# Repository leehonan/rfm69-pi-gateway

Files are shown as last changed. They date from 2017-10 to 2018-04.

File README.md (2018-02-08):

# Meterman Gateway (RFM69-to-Pi Gateway)

This repo contains PCB designs and firmware for a 'meter gateway' that communicates with one or more 'meter nodes' over packet radio.  It acts as a radio gateway between these and logic running on a local server.  Hardware consists of a ATMEGA 328P (with RFM69 radio), and a daughterboard to mate to a Raspberry Pi for Serial UART TX/RX and power (AKA a Pi Hat).  The PCB design could be used for a general-purpose RFM69-Pi Gateway, hacking the firmware code as needed.

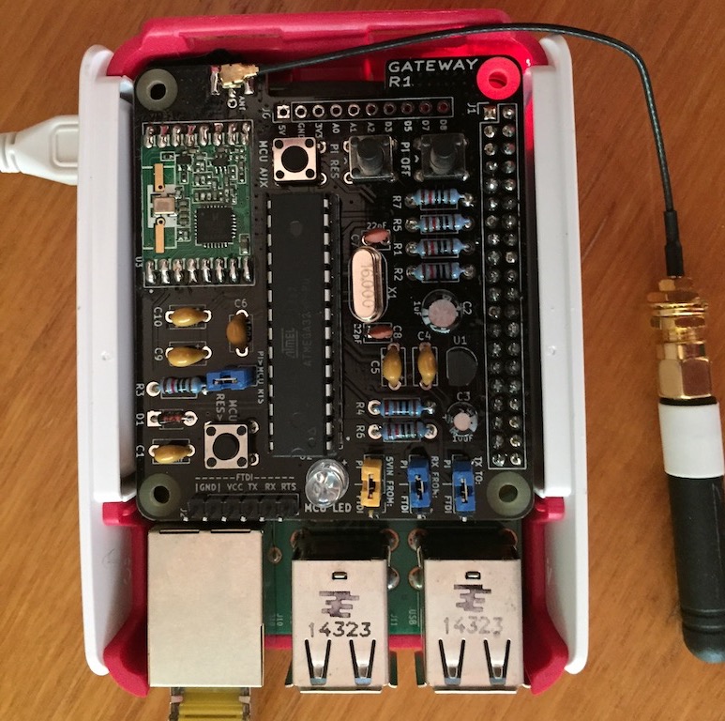
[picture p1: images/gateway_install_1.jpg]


(Note that as above a proper case is TBC)

This Gateway is part of a basic electricity monitoring system described at http://leehonan.com/meterman.  The 'MeterMan' system consists of:

* One or more [MeterNodes](https://github.com/leehonan/meterman-node), transmitting energy consumption at set intervals using sub-GHz packet radio (RFM69 @ 434/868/915MHz).

* The Gateway, being a Raspberry Pi 'Hat' that bridges the RFM69 network to a Raspberry Pi's UART Serial interface.

* A [Server](https://github.com/leehonan/meterman-server) that runs on the Pi, maintains energy consumption data, and provides access to this and other operational data through an API, a file journal, and a realtime socket API (socket API is TBD).

## This Repo

This (Gateway) repo consists of:

* The Gateway PCB design (authored in KiCad).  This mounts onto a Raspberry Pi, with ~12mm x 2.5mm spacers being recommended.

* 3D shape files (.STL) for the gateway housing (WIP).

* Source code for the Gateway firmware (AVR C with Arduino extensions).  

All contents are licenced according to the MIT licence.

## Gateway Overview
The Gateway is essentially a bridge between nodes on a RFM69 network and a local application connected to the Pi's UART serial port.  As the Gateway has been designed to support MeterNodes, much of the context for it is best understood by consulting the more comprehensive [MeterNode's ReadMe](https://github.com/leehonan/meterman-node/blob/master/readme.md) - it is not repeated here (DRY).

The Gateway itself comprises:
* A DC power sub-circuit, switchable using a jumper between 5V from the Raspberry Pi and FTDI (or off if no FTDI connection).  Uses a MCP1700 regulator to supply 3.3VDC.  

* An ATMega 328P MCU sub-circuit, along the lines of common 'minimal low-power Arduino' circuits.  FTDI Header for programming and control.

* A radio sub-circuit with an RFM69HW module.  The design uses an RP-SMA connector, but the PCB also supports uFL or a wire antenna.

The gateway does not have a 'real' RTC.  A timer-based clock is implemented in firmware, although this relies on regular synchronisation with its NTP-synced Pi (e.g. every 15m) to be accurate.

## Operation

 The Gateway:
* Polls for radio messages from nodes, responding to these as needed.  These may indicate events or status changes, which are passed through to the connected application (such as a meter update event).

* Keeps a register of meter nodes, maintaining state information and notifying the connected application when they appear to go offline.

* Polls for serial messages from the connected application, responding to these as needed.  Some of these will cause a particular instruction to be sent to a MeterNode(s) when they are available (e.g. to change their meter value).

* Sends messages to the connected application, such as a request from the Gateway to sync its clock.

The gateway runs continuously and does not sleep.  Its availability for radio messaging can therefore be depended upon by MeterNodes - hence all communication between MeterNodes and their Gateway is initiated by the MeterNodes.

### Gateway Hardware Interface
The MeterNode PCB has the following switches, buttons, headers, and adjustable components.  These are shown below.

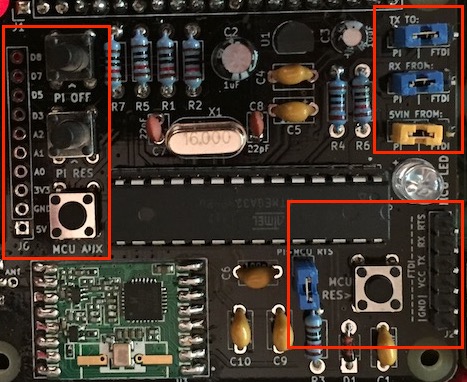
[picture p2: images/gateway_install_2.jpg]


* A group of 3 jumpers that toggle between the Pi and FTDI for TX from the MCU, RX by the MCU, and 5VDC In.  If the jumper is in the FTDI position but FTDI is not connected the device will be off.  Conversely if the switch is in the Pi position but a FTDI adapter is connected, power will be drawn from the Pi (with other FTDI functions working as normal).

* A 'Pi Off' button that shuts the Pi down (using the accompanying pi-gw-reboot script).

* A 'Pi Res' button that reboots the Pi (using the accompanying pi-gw-reboot script).

* A MCU Reset button that reboots the MCU.

* A MCU Aux button that can be programmed as needed (currently blinks LED).

* A jumper to allow the Pi to reboot the MCU (used when programming the MCU, safe to leave closed).

* An FTDI header for use with a USB-FTDI adapter.  This is used to upload firmware and also to interact with the MCU directly over a serial connection (viewing events and using the MeterNode's command protocol to view information and change settings).  Firmware can be uploaded using avrdude directly, or via an IDE (such as platform.io).  The use of the FTDI header is usually unnecessary with a Pi connected as all commands/operations can be performed from the Pi using its GPIO pins (assuming the enclosed scripts are installed).

* A breakout header that is used for setup and diagnosis, typically with a multimeter.  These can also be used for hacking together custom solutions.  The positions are described below and pictured above:

| Position | Description |
| :--- |:---|
| A0 - D8 | Access to unused analogue (A0 - A2) and digital (D3-D8) pins on the MCU. |
| GND | DC Ground. |
| 3V3 | 3.3VDC from regulator.  |
| 5V  | ~5VDC from Pi.  |

### Shutdown and Reboot
The Restart/Reboot and Shutdown buttons are connected to GPIO P23 and P24 (board numbering).  They perform a soft reboot or shutdown, equivalent to a `reboot` or `shutdown -h now`.

The enclosed pishutdown.py script needs to be installed for these to function, and to be set to start at boot.

A service script is enclosed in `/src`.  This can be installed as follows:
```
cp pishutdown.service /lib/systemd/system
chmod 644 /lib/systemd/system/pishutdown.service
systemctl daemon-reload
systemctl enable pishutdown.service
systemctl start pishutdown.service
```

Otherwise simple way to start on boot is to use cron, e.g.:
```
@reboot /usr/local/bin/python3.6 /home/pi/pishutdown.py
```

### Uploading Firmware
Firmware is uploaded using avrdude (alternately through an IDE such as atom/platform.io, the Arduino IDE may work too).  For an FTDI adapter with Id A403JXEV on OSX or Linux the command will be something like:

```
sudo avrdude -c arduino -p atmega328p -P /dev/cu.usbserial-A403JXEV -b 115200 -U flash:w:/home/tmp/firmware.hex
```
In practice for the gateway, it is easiest to upload firmware using scp and then to flash over the GPIO header using avrdude.  E.g.
```
scp /Users/lee/meter_gateway/firmware.hex meterman@meterbox:

sudo avrdude -c arduino -p atmega328p -P /dev/serial0 -b 115200 -U flash:w:/home/meterman/firmware.hex
```

For this to work, avrdude needs to be patched to work around the absence of a DTR pin on the RPi.  The files are enclosed in this repo's `/src` directory, and can be installed using the following commands (as sudo), or by executing the meterman setup script (from the meterman repo) on the pi.
```
cp autoreset /usr/bin
cp avrdude-autoreset /usr/bin
chmod +x /usr/bin/autoreset
chmod +x /usr/bin/avrdude-autoreset
mv /usr/bin/avrdude /usr/bin/avrdude-original
ln -s /usr/bin/avrdude-autoreset /usr/bin/avrdude
```

The flash process will only work if there are no active serial sessions on the port chosen.  Flashing fails occasionally for no clear reason, but will work when retried.

### Serial Communication & Console
A serial connection can be made using a baud of 115200bps, 8N1 (8 data bits, no parity bit, 1 stop bit).  

On the RPi minicom can be used (as can screen etc) to open a terminal:
```
sudo minicom -b 115200 -o -D /dev/serial0
```
Ensure that hardware flow control is off.

The following commands are available through the serial console (case-insensitive):

| Command | Description |
| :--- |:---|
| help | Prints a list of commands. |
| z  | Toggles sleep on and off. |
| dumpg | Prints (dumps) Gateway config and status to the console.  |
| dumpn | Prints (dumps) node status to the console (with dumpn=[node_id] to specify a node).  |
| rcfg | Reset Config.  Resets configuration values stored in EEPROM to defaults and re-applies these.  |
| time | Prints current time from RTC. Set using time=[seconds since UNIX epoch, UTC] |
| logl | Prints log level - ERROR, WARN, INFO, DEBUG.  Set with logl=[log level]|
| ekey | Prints encryption key (16 byte AES) used by network participants for radio comms.  Set with ekey=[encryption key], e.g. ekey=CHANGE_THIS_ASAP|
| neti | Prints Gateway's Network Id comprised of octets akin to an IP address but with an extra subnet (as the 4 octets define a subnet, with node addressing within this).  Set with neti=[network_id].  At least two octets need to be non-zero so 0.0.1.1 is the 'lowest' usable network subnet.  E.g. neti=0.0.1.1|
| gwid | Prints the 'node id' for the gateway.  This should be 1 by convention, but can be any unallocated address from 1 to 253. Set with gwid=[gateway Id]|
| txpw | Print/set transmission power (set with TXPW=[tx power in dBi]).  For RFM69W range is -18 to +13, for RFM69HW is -14 to +20. Higher values will use more power. |
| enta | Sets meter nodes to be in alignment mode (set on with ENTA=1, off with ENTA=0). When on, a change to a MeterNode's RTC will cause it to wait until mm:00 before opening a new entry.  |

### Pi-to-Gateway Serial Message Protocol
The serial port is also used for communication between the Pi and the Gateway.  In normal operation the user-driven command protocol should be unnecessary, as all key functions are exposed through this interface (intended to be used by the Meterman server application).

Messages are distinguished from user commands and user feedback/logging by a prefix:
* for a message from the Gateway to the Pi Server ```G>S:<message>```

* for a message from the Pi Server to the Gateway ```S>G:<message>```

| Message | From | To | Description|
| :--- |:---| :--- |:---|
| Get Time  | gateway | server | Request for server to return time, allowing gateway to sync its internal clock. <br>Format: `GTIME`<br>E.g.: `GTIME` |
| Set Time | server | gateway | Instruction to gateway to set its clock to the time provided (seconds since UNIX epoch) <br>Format: `STIME;<new_epoch_time_utc>`<br>E.g.: `STIME;1502795790`|
| Set Time Ack  | gateway | server | Acknowledges receipt of valid instruction.<br>Format: `STIME_ACK`<br>E.g.: `STIME_ACK` |
| Set Time Nack  | gateway | server | Negative acknowledgement of set time instruction, likely malformed. <br>Format: `STIME_NACK`<br>E.g.: `STIME_NACK` |
| Get Gateway Snapshot | server | gateway | Request for gateway status dump. <br>Format: `GGWSNAP`<br>E.g.: `GGWSNAP` |
| Gateway Snapshot | gateway | server | Dump of Gateway Status <br>Format: `GWSNAP;<gateway_id>,<when_booted>,<free_ram>,<time>,<log_level>,<encrypt_key>,<network_id>,<tx_power>`<br>E.g.: `GWSNAP;1,1496842913428,577,1496842913428,DEBUG,PLEASE_CHANGE_ME,0.0.1.1,13` |
| Get Node Snapshot | server | gateway | Requests a dump of a node's state from the Gateway.  All nodes observed by the gateway since boot will be returned (there is no registration process - any with correct subnet and key are assumed to be valid members). <br>Format: `GNOSNAP;<node_id> - returns all nodes if no node_id or node_id=254`<br>E.g.: `GNOSNAP;2` |
| Node Snapshot | gateway | server | A snapshot of one or more nodes, delimited by ';'. <br>Format: `NOSNAP;[1..n of [<node_id>,<batt_voltage>,<up_time>,<sleep_time>,<free_ram>,<when_last_seen>,<last_clock_drift>,<meter_interval>,<meter_impulses_per_kwh>,<last_meter_entry_finish>,<last_meter_value>,<puck_led_rate>,<puck_led_time>,<last_rssi_at_gateway>]]`<br>E.g.: `NOSNAP;2,4500,15000,20000,600,1496842913428,500,5,1496842913428,3050,1,100,1000,-70` |
| Get Node Snapshot Nack | gateway | server | Negative acknowledgement of request, likely malformed. <br>Format: `GNOSNAP_NACK;<node_id>`<br>E.g.: `GNOSNAP_NACK;2` |
| Meter Update - with Current | gateway | server | Pass-through of message from meterman node, with envelope. <br>Format: `MUPC;<node_id>,<MUPC radio message>`<br>E.g.: `MUPC;2,MUPC,1496842913428,18829393;15,1,10.2;15,5,10.7;` |
| Meter Update - without Current | gateway | server | Pass-through of message from meterman node, with envelope. <br>Format: `MUP_;<node_id>,<MUP_ radio message>`<br>E.g.: `MUP_;2,MUP_,1496842913428,18829393;15,1;15,5;15,2;16,3;` |
| Meter Rebase | gateway | server | Pass-through of message from meterman node, with envelope. <br>Format: `MREB;<node_id>,<MREB radio message>`<br>E.g.: `MREB;2,MREB,1496842913428,18829393` |
| General Message (Broadcast) | gateway | server | Pass-through of message from meterman node, with envelope. <br>Format: `GMSG;<node_id>,<GMSG radio message>`<br>E.g.: `GMSG;2,GMSG,message` |
| Set Meter Value | server | gateway | Requests a reset of a node's meter value to the watt-hour value specified <br>Format: `SMVAL;<node_id>,<new_meter_value>`<br>E.g.: `SMVAL;2,10` |
| Set Meter Value Ack | gateway | server | Acknowledges receipt of valid instruction. <br>Format: `SMVAL_ACK;<node_id>`<br>E.g.: `SMVAL_ACK;2` |
| Set Meter Value Nack | gateway | server | Negative acknowledgement of request, likely malformed. <br>Format: `SMVAL_NACK;<node_id>`<br>E.g.: `SMVAL_NACK;2` |
| Set Puck LED | server | gateway | Requests a change of a node's puck LED rate and time. <br>Format: `SPLED;<node_id>,<new_puck_led_rate>,<new_puck_led_time>`<br>E.g.: `SPLED;2,1,100` |
| Set Puck LED Ack | gateway | server | Acknowledges receipt of valid instruction. <br>Format: `SPLED_ACK;<node_id>`<br>E.g.: `SPLED_ACK;2` |
| Set Puck LED Nack | gateway | server | Negative acknowledgement of request, likely malformed. <br>Format: `SPLED_NACK;<node_id>`<br>E.g.: `SPLED_NACK;2` |
| Set Meter Interval | server | gateway | Requests a change of a node's metering interval to the value specified.  The interval is the period in seconds at which meter entries are created i.e. (resolution). <br>Format: `SMINT;<node_id>,<new_meter_interval>`<br>E.g.: `SMINT;2,10` |
| Set Meter Interval Ack | gateway | server | Acknowledges receipt of valid instruction. <br>Format: `SMINT_ACK;<node_id>`<br>E.g.: `SMINT_ACK;2` |
| Set Meter Interval Nack | gateway | server | Negative acknowledgement of request, likely malformed. <br>Format: `SMINT_NACK;<node_id>`<br>E.g.: `SMINT_NACK;2` |
| Set GITR | server | gateway | Sends request to gateway to set node's gateway instruction polling rate to more aggressive value for a temporary period <br>Format: `SGITR;<node_id>,<tmp_poll_rate>,<tmp_poll_period>`<br>E.g.: `SGITR;2,30,300` |
| Set GITR Ack | gateway | server | Acknowledges receipt of valid instruction. <br>Format: `SGITR_ACK;<node_id>`<br>E.g.: `SGITR_ACK;2` |
| Set GITR Nack | gateway | server | Negative acknowledgement of request, likely malformed. <br>Format: `SGITR_NACK;<node_id>`<br>E.g.: `SGITR_NACK;2` |
| Node Dark Alert | gateway | server | One-time alert on node going from seen to 'missing' after configured period <br>Format: `NDARK;<node_id>,<last_seen>`<br>E.g.: `NDARK;2,1496842913428` |

### Radio Protocol
See the <a href="https://github.com/leehonan/meterman-node/blob/master/readme.md#radio-protocol">MeterNode Radio Protocol documentation</a>.

## Implementation - Gateway Firmware
For simplicity, the firmware is implemented as a single C++ program (no header file), although it will need supporting libraries to compile.  There is some redundancy versus the companion meternode firmware - the common components may be moved to a library.  Some Arduino library features are used.

The firmware requires a 328P that has been flashed with Optiboot.  It uses about 90% available program flash memory.

Depending on configuration, about 500 bytes RAM will remain free at runtime (on average, of 2K).  

There are a number of configuration settings at the beginning of the source code.  Particular attention should be paid to the 'Main Config Parameters'.

Note that a version is set in the firmware, and broadcast on boot.

The code is fairly well-documented so isn't covered further here.

## Implementation - PCBs & Cases

The Gateway PCB measures 65x56mm, being a standard Raspberry Pi Hat size.

A case for the Pi and Gateway is TBD, currently I use a regular Pi case and tape the antenna to it.

Of course, the MeterNode and Gateway antennae should be in the same orientation to maximise signal strength.

### Gateway Schematic & PCB

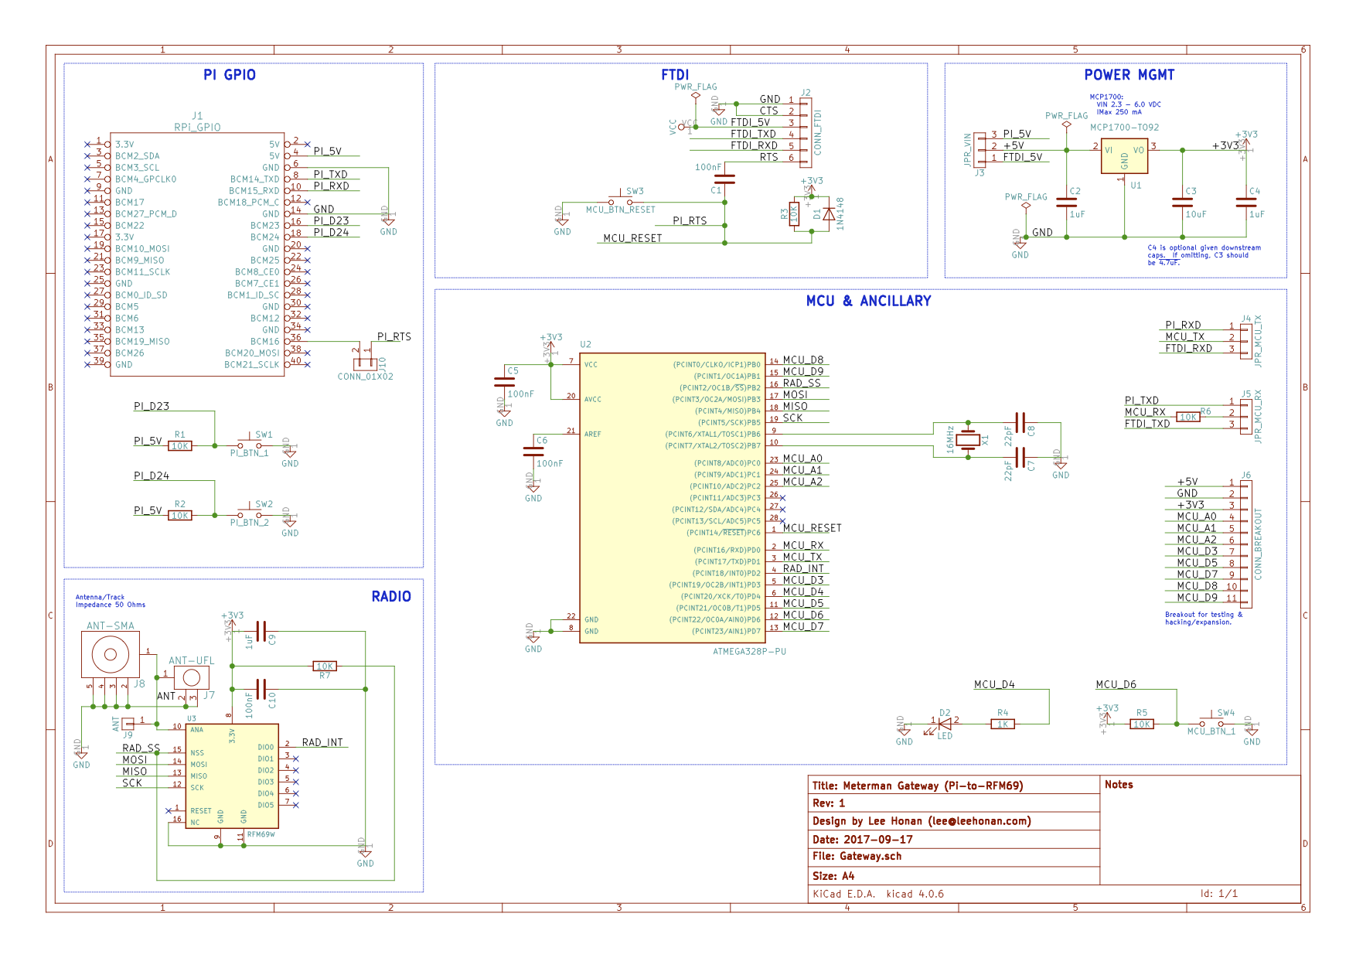
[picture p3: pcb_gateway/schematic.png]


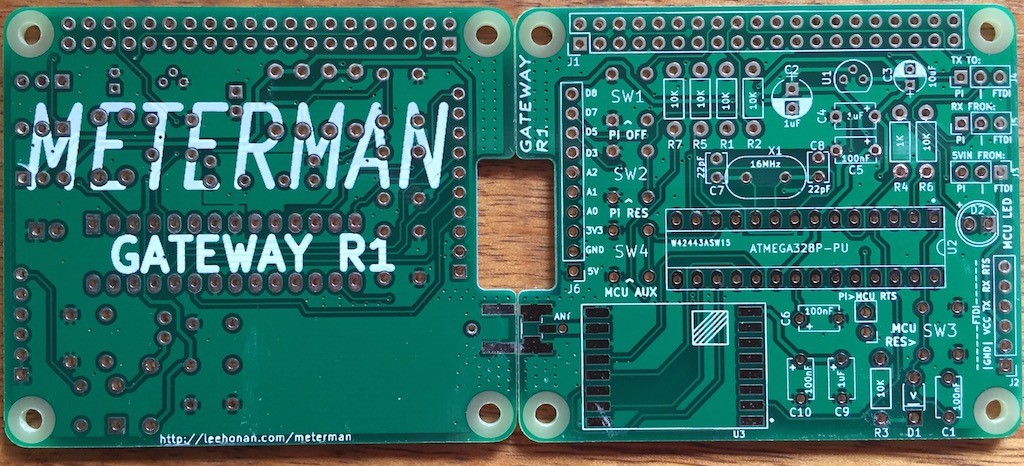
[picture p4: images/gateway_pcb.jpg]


The PCB design minimises the use of SMT components, and uses through-hole instead.  It is 'hobbyist-friendly' with the only SMT component being the easily-solderable RFM69 and the slightly fiddly uFL connector.  

Highlights:

* The MCP1700 regulator (3.3V) was chosen for consistency with the MeterNode.

* Unlike the MeterNode, I usually use a uFL connector here.  Of course a RP-SMA connector, or even a wire of the appropriate length can be used instead.

* Any RFM69W or RFM69HW module will work.  I use the RFM69HW here (as opposed to the MeterNode's RFM69W) because it is cheaper and there is no need to minimise power consumption on the gateway.

* Of course, the Pi's 2x20 GPIO header needs to face downward (towards the Pi).  Be mindful of this when assembling.

### Parts List

Approx total is USD$11 (not including labour!).  That assumes you purchase common parts in quantity from Chinese suppliers (e.g. resistors, capacitors).  Otherwise cost will be radically higher.  

| Part | Qty | Approx <br>Item Cost<br>(USD) | Comments |
|:---| :--- |:---|:---|
| PCB | 1 | $0.50 | E.g. 10 for $5 at PCBWay |
| Case | 1 | $0.50 | 3D-printed, PLA |
| LED | 1 | $0.02 | Super-bright 5mm, 20mA |
| RP-SMA 3dbi Antenna | 1 | $2.90 | I use higher quality ones via RocketScream, cheaper options available. |
| uFL Connector w/ pigtail | 1 | $1.00 |  |
| MCP1700 Regulator | 1 | $0.50 | 3.3V, TO-92 |
| MCU - ATMEGA 328P | 1 | $1.80 | DIP-28, with holder |
| 16MHz Crystal | 1 | $0.20 | |
| RFM69HW Module | 1 | $2.50 | SMD |
| Resistor - 1 KOhm | 1 | $0.01 | 0.25W |
| Resistor - 10 KOhm | 6 | $0.01 | 0.25W |
| Capacitor - 22 pF | 2 | $0.01 | Ceramic disc |
| Capacitor - 100 nF | 4 | $0.01 | Monolithic, Ceramic |
| Capacitor - 1 uF | 1 | $0.02 | Electrolytic |
| Capacitor - 1 uF | 2 | $0.01 | Monolithic, Ceramic |
| Capacitor - 10 uF | 1 | $0.02 | Electrolytic, 4x7mm |
| Diode - 1N4148 | 1 | $0.01 |  |
| 6x6mm pushbutton | 4 | $0.02 |  |
| Pin Header | 1 | $0.02 | 6P, 2.54mm pitch |
| Pin Header | 3 | $0.01 | 3P, 2.54mm pitch |
| Pin Header | 1 | $0.01 | 2P, 2.54mm pitch |
| Jumper Cap | 4 | $0.01 | 2P, 2.54mm pitch |
| Pi GPIO Header | 1 | $0.10 | 2x20, 40P, 2.54mm pitch |

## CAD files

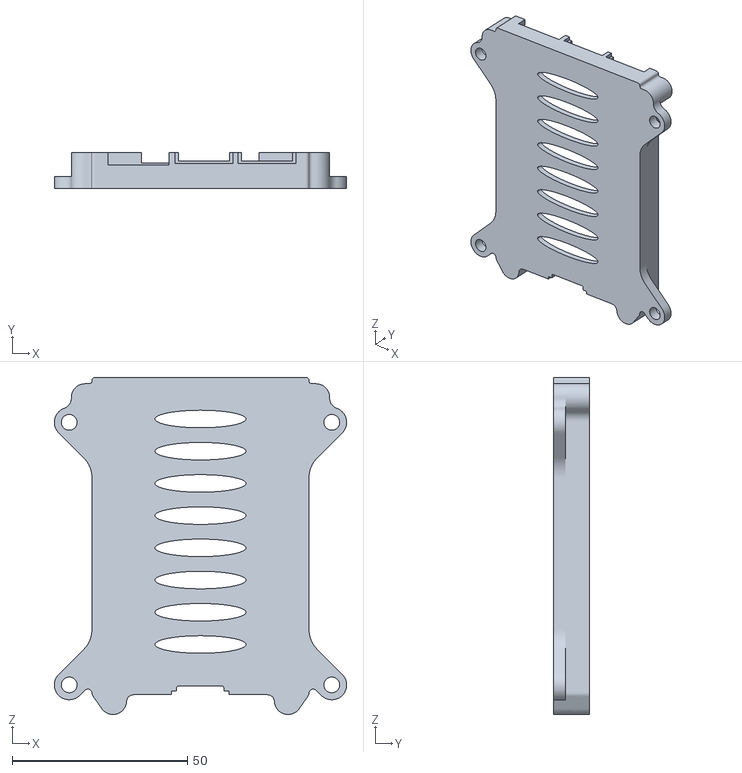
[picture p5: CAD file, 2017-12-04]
pcb_gateway/3D Parts/Base.stl
83.5 x 10.3 x 96.2

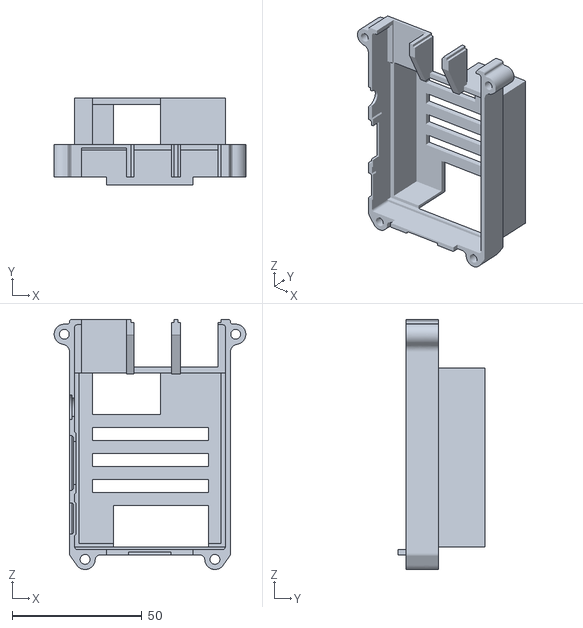
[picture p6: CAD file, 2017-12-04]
pcb_gateway/3D Parts/Lid.stl
73.8 x 33.5 x 96.3

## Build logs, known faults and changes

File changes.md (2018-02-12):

# Change Log

Release/revision numbering is major only, no minors - i.e. 1,2,3... not 1.1, 1.2, 2.0, etc.

#### 2017-11-27 R6
* Baseline release to GitHub (from private repo).

#### 2018-01-22 R8
* Changed sscanf calls to use SCNu8 macro for uint_8t vars, SCNd8 macro for int_8t vars

#### 2018-02-06 R9
* Reduced default modem baud rate to 9.6kbps

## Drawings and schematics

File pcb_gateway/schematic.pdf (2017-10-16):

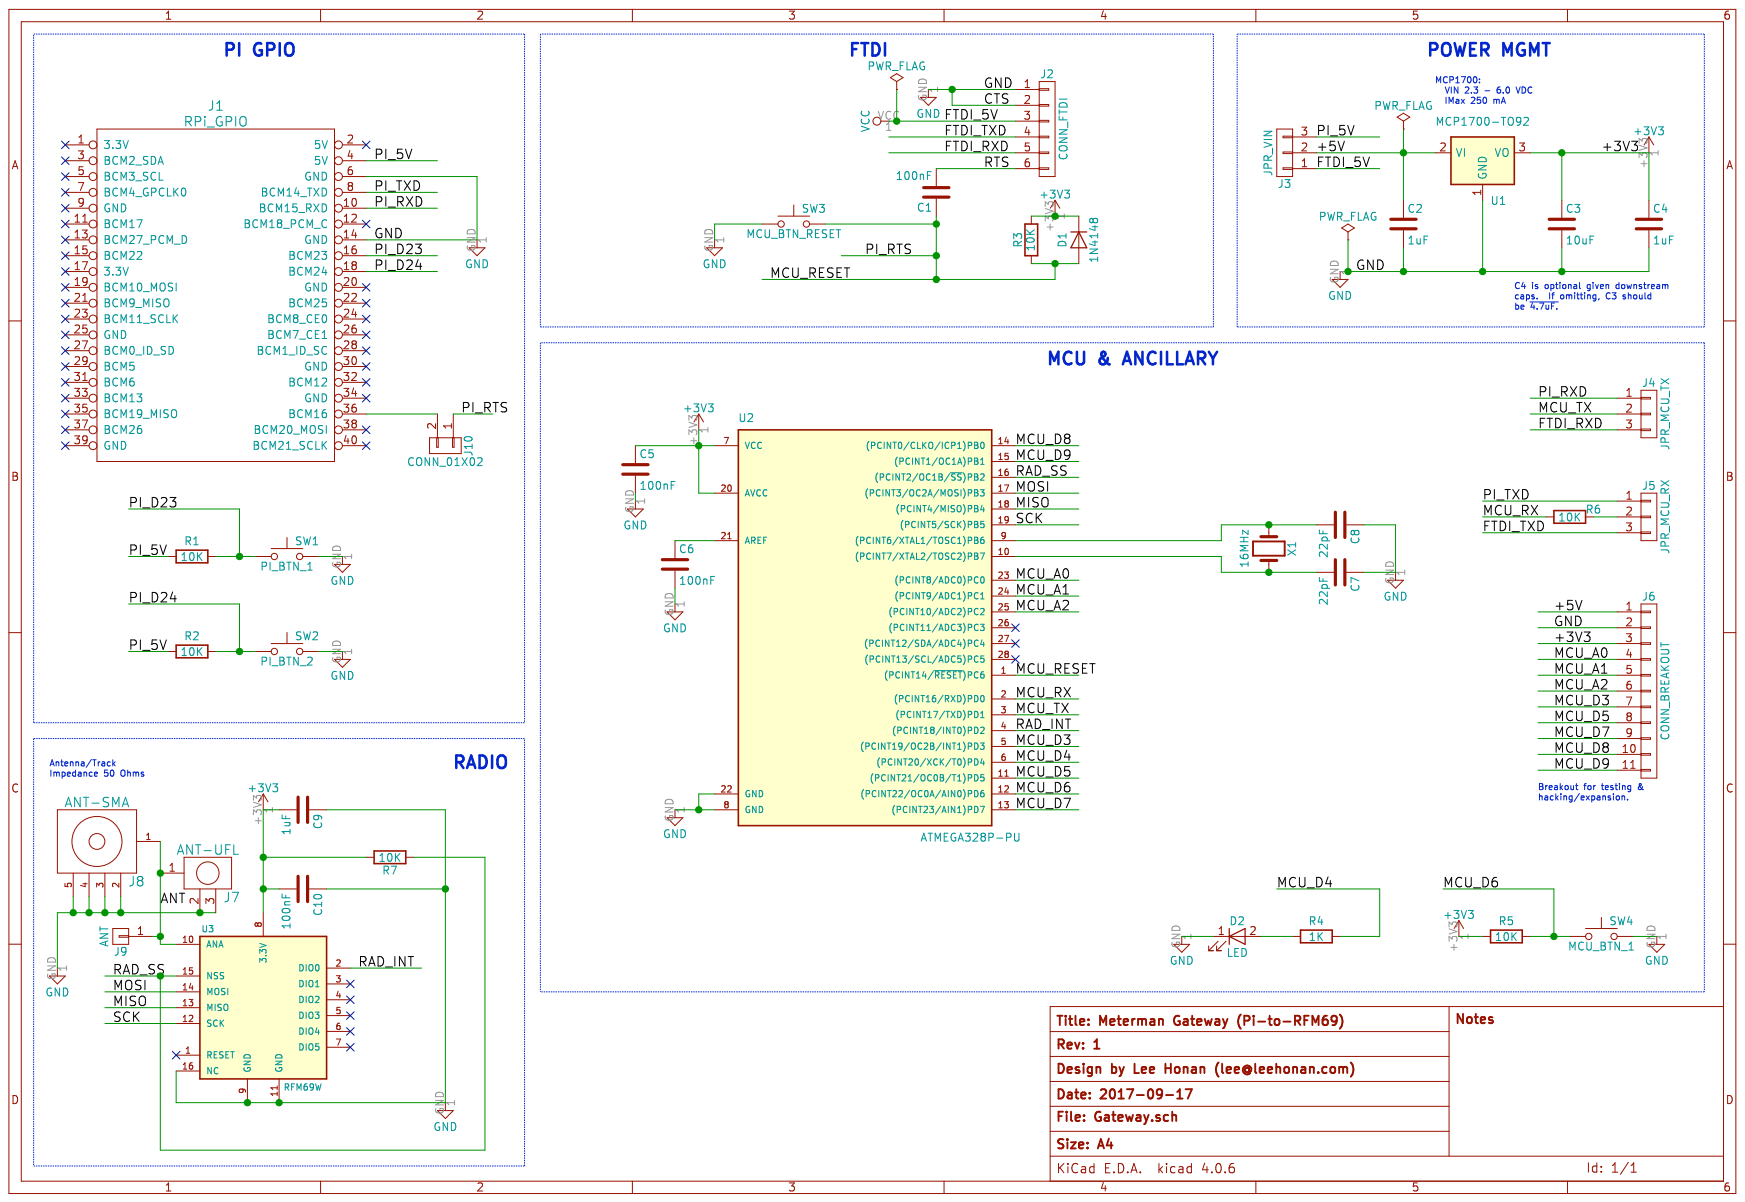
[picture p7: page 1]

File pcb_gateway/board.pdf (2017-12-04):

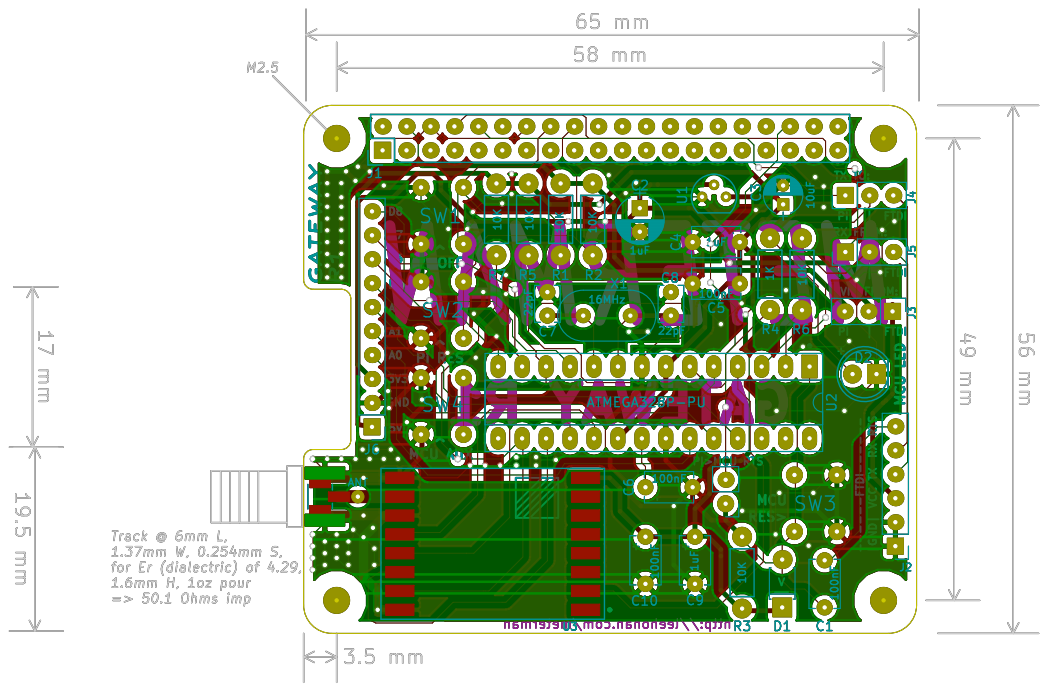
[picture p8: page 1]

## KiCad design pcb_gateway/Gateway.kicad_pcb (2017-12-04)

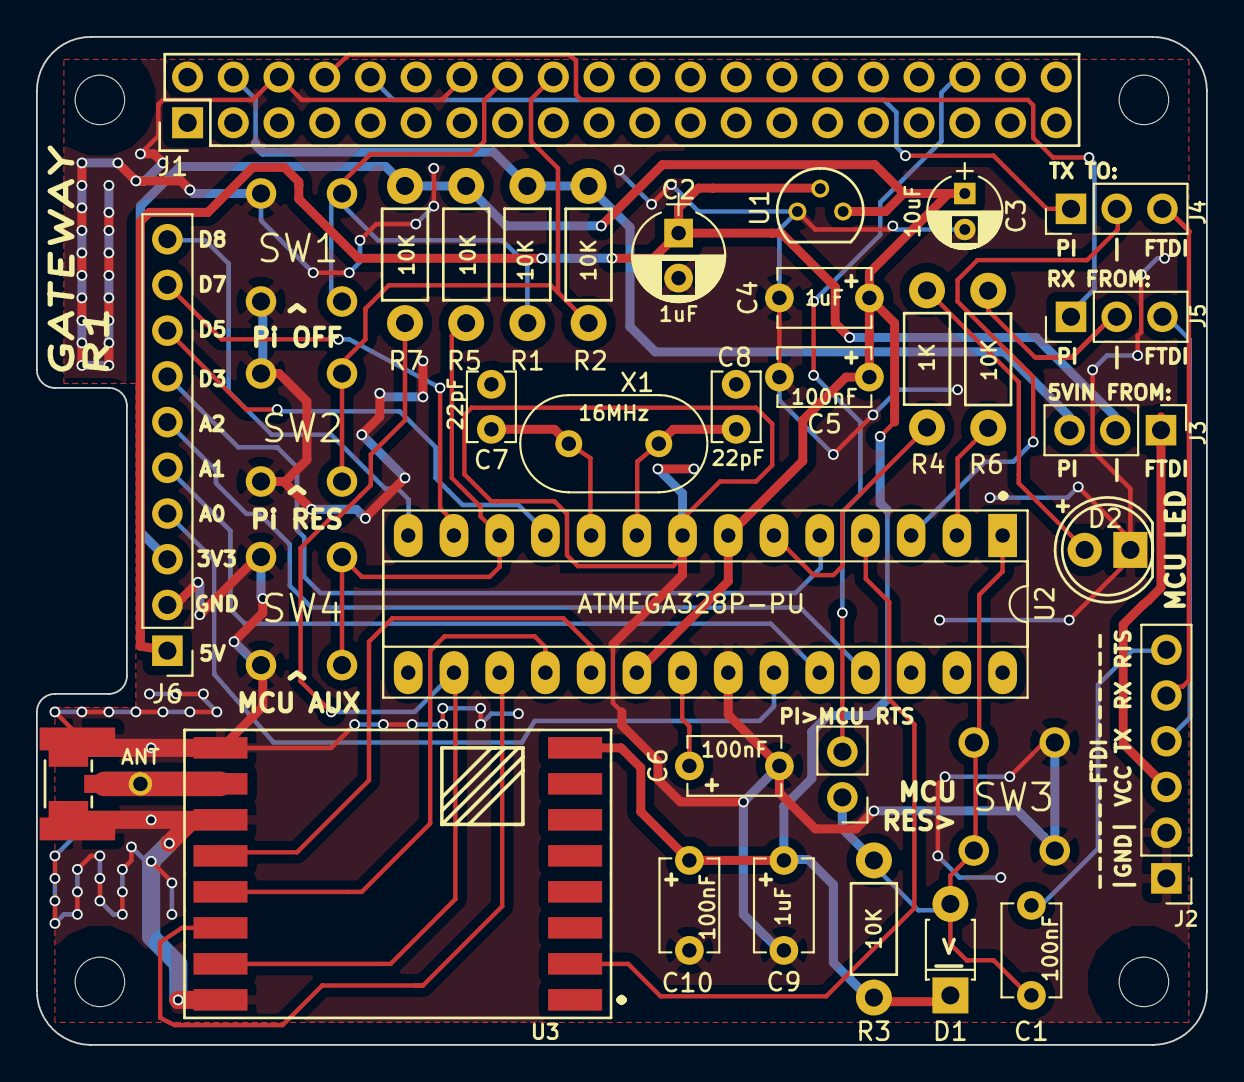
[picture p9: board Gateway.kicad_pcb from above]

Board: 2 copper layers, 65.0 x 56.0 mm, 37 parts (0 on the bottom side), 36 nets.

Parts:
C1, C5, C6, C10: 100nF; C_Disc_D5.1mm_W3.2mm_P5.00mm
C2: 1uF; CP_Radial_D5.0mm_P2.50mm
C3: 10uF; CP_Radial_D4.0mm_P2.00mm
C4, C9: 1uF; C_Disc_D5.1mm_W3.2mm_P5.00mm
C7, C8: 22pF; C_Disc_D3.8mm_W2.6mm_P2.50mm
D1: 1N4148; D_T-1_P5.08mm_Horizontal
D2: LED; LED-5MM
J1: RPi_GPIO; Pin_Header_Straight_2x20
J2: CONN_FTDI; Pin_Header_Straight_1x06_Pitch2.54mm
J3: JPR_VIN; Pin_Header_Straight_1x03_Pitch2.54mm
J4: JPR_MCU_TX; Pin_Header_Straight_1x03_Pitch2.54mm
J5: JPR_MCU_RX; Pin_Header_Straight_1x03_Pitch2.54mm
J6: CONN_BREAKOUT; Pin_Header_Straight_1x10_Pitch2.54mm
J7: ANT-UFL; U.FL-R-SMT
J8: ANT-SMA; RF-SMA-EDGE
J9: ANT; Pin_Header_Straight_1x01
J10: CONN_01X02; Pin_Header_Straight_1x02_Pitch2.54mm
R1, R2, R3, R5, R6, R7: 10K; Resistor_Horizontal_RM7mm
R4: 1K; Resistor_Horizontal_RM7mm
SW1: PI_BTN_1; 6x6mm_pushbutton
SW2: PI_BTN_2; 6x6mm_pushbutton
SW3: MCU_BTN_RESET; 6x6mm_pushbutton
SW4: MCU_BTN_1; 6x6mm_pushbutton
U1: MCP1700-TO92; TO-92_Molded_Narrow
U2: ATMEGA328P-PU; DIP-28_W7.62mm_Socket_LongPads
U3: RFM69W; RFM69HW_SMD_Handsoldering
X1: 16MHz; Resonator-2pin_w10.0mm_h5.0mm

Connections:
+3V3: C3.1, C4.1, C5.1, C9.2, C10.2, D1.1, J6.3, R3.2, R5.2, R7.2, U1.3, U2.7, U2.20, U3.8
/+5V: C2.1, J3.2, J6.1, U1.2
/ANT: J7.1, J9.1, U3.10
/FTDI_RXD: J2.5, J4.3
/FTDI_TXD: J2.4, J5.3
/MCU_A0: J6.4, U2.23
/MCU_A1: J6.5, U2.24
/MCU_A2: J6.6, U2.25
/MCU_D3: J6.7, U2.5
/MCU_D4: R4.1, U2.6
/MCU_D5: J6.8, U2.11
/MCU_D6: R5.1, SW4.1, U2.12
/MCU_D7: J6.9, U2.13
/MCU_D8: J6.10, U2.14
/MCU_RESET: C1.1, D1.2, J10.1, R3.1, SW3.2, U2.1
/MCU_RX: R6.2, U2.2
/MCU_TX: J4.2, U2.3
/MISO: U2.18, U3.13
/MOSI: U2.17, U3.14
/PI_5V: J1.4, J3.3, R1.2, R2.2
/PI_D23: J1.16, R1.1, SW1.1
/PI_D24: J1.18, R2.1, SW2.1
/PI_RXD: J1.10, J4.1
/PI_TXD: J1.8, J5.1
/RAD_INT: U2.4, U3.2
/RAD_SS: R7.1, U2.16, U3.15
/RTS: C1.2, J2.6
/SCK: U2.19, U3.12
GND: C2.2, C3.2, C4.2, C5.2, C6.2, C7.1, C8.1, C9.1, C10.1, D2.1, J1.6, J1.14, J2.1, J2.2, J6.2, J7.2, J7.3, J8.2, J8.3, J8.4, J8.5, SW1.2, SW2.2, SW3.1, SW4.2, U1.1, U2.8, U2.22, U3.9, U3.11, U3.16
unnamed: C6.1, U2.21
unnamed: C7.2, U2.10, X1.2
unnamed: C8.2, U2.9, X1.1
unnamed: D2.2, R4.2
unnamed: J1.36, J10.2
unnamed: J5.2, R6.1
VCC: J2.3, J3.1

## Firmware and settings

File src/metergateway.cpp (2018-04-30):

/**
    =========
    METERMAN METERGATEWAY
    metergateway.cpp
    =========
    Operates a 'meter gateway' that communicates with one or more 'meter nodes'
    over packet radio.  It acts as a radio gateway between these and logic
    running on a local server.  Hardware consists of a ATMEGA 328P (with RFM69
    radio), and a daughterboard to mate to a Raspberry Pi for Serial TX/RX and
    power (AKA a Pi Hat).

    This gateway could aggregate multiple nodes. These are part of a basic
    monitoring system as described at http://leehonan.com/meterman.

    Uses following libraries (with licencing):  RadioHead (GPL Version 2
    Licence), and Time (GPL 2.1).

    This program is licenced as follows.

    -----------
    MIT License
    -----------

    Copyright (c) 2017 Lee Honan (lee at leehonan dot com).

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
    THE SOFTWARE IS PROVIDED "AS IS", WITHOUT WARRANTY OF ANY KIND, EXPRESS OR
    IMPLIED, INCLUDING BUT NOT LIMITED TO THE WARRANTIES OF MERCHANTABILITY,
    FITNESS FOR A PARTICULAR PURPOSE AND NONINFRINGEMENT. IN NO EVENT SHALL THE
    AUTHORS OR COPYRIGHT HOLDERS BE LIABLE FOR ANY CLAIM, DAMAGES OR OTHER
    LIABILITY, WHETHER IN AN ACTION OF CONTRACT, TORT OR OTHERWISE, ARISING
    FROM, OUT OF OR IN CONNECTION WITH THE SOFTWARE OR THE USE OR OTHER DEALINGS
    IN THE SOFTWARE.
 */

// *****************************************************************************
//    Main Config Parameters
//    'DEF_*' constants are defaults for configuration variables of the same
//    name. Most of these will be stored to EEPROM and can be updated by
//    serial terminal commands.

//    Have minimised use of #DEFINE, #IFDEF etc for easier debugging.
// *****************************************************************************

#include <Arduino.h>
#include <avr/wdt.h>
#include <EEPROM.h>

// http://www.airspayce.com/mikem/arduino/RadioHead/
#include <RH_RF69.h>
#include <RHReliableDatagram.h>

// https://github.com/PaulStoffregen/Time
#include <TimeLib.h>


static const int8_t FW_VERSION = 10;

// Log Levels
typedef enum {
    logNull = 0,        // outputs to serial regardless of runtime log level
    logError = 1,
    logWarn = 2,
    logInfo = 3,
    logDebug = 4
} LogLev;

// Default runtime log level.
// Can control through serial command, save to EEPROM.
static const LogLev DEF_LOG_LEVEL = logDebug;

// if using HW/HCW module must set to true:
static const bool RADIO_HIGH_POWER = true;

// Initial power level in dBm.  Use -18 to +13 for W/CW, -2 to +20 for HW/HCW:
static const int8_t DEF_TX_POWER = 19;

// Gateway ID.  Gateway is usually 1.  Nodes between 2 and 254.
// 255 is broadcast (RH_GMSG_ADDRESS).
// Nodes are added dynamically, no pre-registration.
// Implicitly trusted if they have the same network Id and key.
static const uint8_t DEF_GATEWAY_ID = 1;

// Network octets, akin to IP address but with an extra subnet (as the 4 octets
// define a subnet, with node addressing within this).
// Need at least 2 octets to be non-zero, so will have 3rd and 4th begin at 1.
static const uint8_t DEF_NETWORK_ID_O1 = 0;  //0 to 254
static const uint8_t DEF_NETWORK_ID_O2 = 0;  //0 to 254
static const uint8_t DEF_NETWORK_ID_O3 = 1;  //1 to 254 by convention
static const uint8_t DEF_NETWORK_ID_O4 = 1;  //1 to 254 by convention

// AES 128b encryption key, shared amongst nodes.  Must be 16 chars/bytes,
// chars ASCII 32 - 126 (space, symbols, letters, numbers).
static const uint8_t KEY_LENGTH = 16;
static const uint8_t DEF_ENCRYPT_KEY[KEY_LENGTH] =
        {'C','H','A','N','G','E','_','M','E','_','P','L','E','A','S','E'};

static const uint32_t SERIAL_BAUD = 115200;

// whether to align node entries to mm:00 (begin at top of minute)
static const bool DEF_ALIGN_ENTRIES = 1;

// *****************************************************************************
//    General Init - Pins
// *****************************************************************************

static const uint8_t RADIO_INTERRUPT_PIN = 2;   // IC4
                                                // uses 328P interrupt 0

static const uint8_t RADIO_SS_PIN = 10;         // IC16
                                                // HIGH is off, LOW on

static const uint8_t LED_PIN = 4;               // IC6

static const uint8_t BUTTON_PIN = 6;            // IC12
                                                // auxiliary button

// *****************************************************************************
//    General Init - General Variables
// *****************************************************************************

// variable to hold MCU reset cause
uint8_t resetFlags __attribute__ ((section(".noinit")));

uint32_t btnEventStartMillis = 0;    // button on start time in millis

// global temporary variables, used somewhat arbitrarily vs local static vars
char tmpStr[60] = "";
uint32_t tmpInt = 0ul;

static const uint8_t SERIAL_IN_BUFFER_SIZE = 40;
char serInBuff[SERIAL_IN_BUFFER_SIZE] = "";
uint8_t serialBuffPos = 0;

// *****************************************************************************
//    General Init - Config Vars
// *****************************************************************************

// Config Variables (corresponding defaults are defined above with DEF_*).  Can
// be changed with serial commands and are saved to EEPROM.
LogLev cfgLogLevel = DEF_LOG_LEVEL;
uint8_t cfgTXPower = 0;
uint8_t cfgGatewayId = 0;
uint8_t cfgNetworkId1 = 0;
uint8_t cfgNetworkId2 = 0;
uint8_t cfgNetworkId3 = 0;
uint8_t cfgNetworkId4 = 0;
uint8_t cfgEncryptKey[KEY_LENGTH] =
        {'\0','\0','\0','\0','\0','\0','\0','\0','\0','\0','\0','\0','\0',
        '\0','\0','\0'};
uint8_t cfgAlignEntries = 0;

// *****************************************************************************
//    General Init - Logging
// *****************************************************************************

// Serial event/status logging output prefixes
static const char LOG_ERROR_LBL[] PROGMEM = "ERROR";
static const char LOG_WARN_LBL[] PROGMEM = "WARN";
static const char LOG_INFO_LBL[] PROGMEM = "INFO";
static const char LOG_DEBUG_LBL[] PROGMEM = "DEBUG";

// *****************************************************************************
//    General Init - Commands (Serial)
// *****************************************************************************

// Serial command strings.
static const char SMSG_FS PROGMEM = ',';
static const char SMSG_RS PROGMEM = ';';

// Serial message (TX) string prefixes.
static const char SMSG_TX_PREFIX[] PROGMEM = "G>S:";
static const char SMSG_GTIME[] PROGMEM = "GTIME";
static const char SMSG_STIME_ACK[] PROGMEM = "STIME_ACK";
static const char SMSG_STIME_NACK[] PROGMEM = "STIME_NACK";
static const char SMSG_GWSNAP[] PROGMEM = "GWSNAP";   // dump of gateway status
static const char SMSG_NOSNAP[] PROGMEM = "NOSNAP";   // one or many nodes
static const char SMSG_GNOSNAP_NACK[] PROGMEM = "GNOSNAP_NACK";
static const char SMSG_MUPC[] PROGMEM = "MUPC";
static const char SMSG_MUP_[] PROGMEM = "MUP_";
static const char SMSG_MREB[] PROGMEM = "MREB";
static const char SMSG_GMSG[] PROGMEM = "GMSG";
static const char SMSG_SMVAL_ACK[] PROGMEM = "SMVAL_ACK";
static const char SMSG_SMVAL_NACK[] PROGMEM = "SMVAL_NACK";
static const char SMSG_SPLED_ACK[] PROGMEM = "SPLED_ACK";
static const char SMSG_SPLED_NACK[] PROGMEM = "SPLED_NACK";
static const char SMSG_SMINT_ACK[] PROGMEM = "SMINT_ACK";
static const char SMSG_SMINT_NACK[] PROGMEM = "SMINT_NACK";
static const char SMSG_SGITR_ACK[] PROGMEM = "SGITR_ACK";
static const char SMSG_SGITR_NACK[] PROGMEM = "SGITR_NACK";
static const char SMSG_NDARK[] PROGMEM = "NDARK";

// Serial message (RX) string prefixes.
static const char SMSG_RX_PREFIX[] PROGMEM = "S>G:";
static const char SMSG_STIME[] PROGMEM = "STIME";
static const char SMSG_GGWSNAP[] PROGMEM = "GGWSNAP";
static const char SMSG_GNOSNAP[] PROGMEM = "GNOSNAP";
static const char SMSG_SMVAL[] PROGMEM = "SMVAL";
static const char SMSG_SPLED[] PROGMEM = "SPLED";
static const char SMSG_SMINT[] PROGMEM = "SMINT";
static const char SMSG_SGITR[] PROGMEM = "SGITR";

// Serial command (RX) strings.

// help
static const char SER_CMD_HELP[] PROGMEM = "HELP";

// dump gateway state to console
static const char SER_CMD_DUMPGW[] PROGMEM = "DUMPG";

// dump node state to console
static const char SER_CMD_DUMPNO[] PROGMEM = "DUMPN";

// reset EEPROM config to defaults
static const char SER_CMD_RCFG[] PROGMEM = "RCFG";

// print/set time (set with TIME=[time as epoch])
static const char SER_CMD_TIME[] PROGMEM = "TIME";

// print/set loglevel (set with LOGL=[log level])
static const char SER_CMD_LOGL[] PROGMEM = "LOGL";

// print/set encryption key (set with EKEY=[key])
static const char SER_CMD_EKEY[] PROGMEM = "EKEY";

// print/set network id (set with NETI=[network id])
static const char SER_CMD_NETI[] PROGMEM = "NETI";

// print/set gateway id (set with GWID=[gateway id])
static const char SER_CMD_GWID[] PROGMEM = "GWID";

// print/set transmission power (set with TXPW=[tx power in dBi])
static const char SER_CMD_TXPW[] PROGMEM = "TXPW";

// print/set entry alignment (set with ENTA=[0,1])
static const char SER_CMD_ENTA[] PROGMEM = "ENTA";

// Array of commands, used to print list on help or invalid input
const char* const SER_CMDS[] PROGMEM = {
                SER_CMD_HELP, SER_CMD_DUMPGW, SER_CMD_DUMPNO, SER_CMD_RCFG,
                SER_CMD_TIME, SER_CMD_LOGL, SER_CMD_EKEY, SER_CMD_NETI,
                SER_CMD_GWID, SER_CMD_TXPW, SER_CMD_ENTA};

// *****************************************************************************
//    General Init - Radio Message Types
// *****************************************************************************

// Meter Rebase
static const char RMSG_MREBASE[] PROGMEM = "MREB";

// Meter Update with current
static const char RMSG_MUPC[] PROGMEM = "MUPC";

// Meter Update without current
static const char RMSG_MUP_[] PROGMEM = "MUP_";

// Instruction Request from Node to Gateway
static const char RMSG_GINR[] PROGMEM = "GINR";

// Request from Gateway to Node to temporarily increase GINR polling rate
static const char RMSG_GITR[] PROGMEM = "GITR";

// Clock Sync Ping Request from Node to Gateway
static const char RMSG_PREQ[] PROGMEM = "PREQ";

// Clock Sync Ping Response from Gateway to Node
static const char RMSG_PRSP[] PROGMEM = "PRSP";

// Meter instruction (from gateway to node) to set meter value
static const char RMSG_MVAI[] PROGMEM = "MVAI";

// Meter instruction (from gateway to node) to set meter interval
static const char RMSG_MINI[] PROGMEM = "MINI";

// Meter instruction (from gateway to node) to set puck LED
static const char RMSG_MPLI[] PROGMEM = "MPLI";

// 'no op' Meter instruction (from gateway to node)
static const char RMSG_MNOI[] PROGMEM = "MNOI";

// General purpose message (can broadcast)
static const char RMSG_GMSG[] PROGMEM = "GMSG";

// Number of seconds to wait for 'proof of life' before regarding a node as MIA,
// and alerting.  Longer than 5m usually best.
static const uint16_t POL_MSG_TIMEOUT_SEC = 600;        //10m

// *****************************************************************************
//    Radio Init
//
//    All message-driven request/response interactions are logically
//    asynchronous; but implemented by RadioHead via synchronous send/ACK
//    message pairs. Messaging initiated by client node to facilitate long sleep
//    periods.  As such, the gateway needs to queue any commands or updates for
//    meter nodes.  Max message data length is 60 *bytes*, with no
//    recognition of payload elements as anything other than a big 'string'.
//    E.g. an uint32_t of 2,000,000,000 will be 80b/10B not 32b/4B.
//
// *****************************************************************************

static const float RADIO_FREQ = 915.0f;

// Modem config per RadioHead docs.  FSK seems most reliable.
//
// From FSK_Rb9_6Fd19_2 through to FSK_Rb125Fd125 work well (could go higher).
// Use fastest rate that yields acceptable range and reasonably low TX power
// (unless running on DC adapter and not concerned with RF 'noise').

//Using FSK, Whitening, bit rate = 9.6kbps, modulation frequency = 19.2kHz.
// static const RH_RF69::ModemConfigChoice MODEM_CONFIG = RH_RF69::FSK_Rb9_6Fd19_2;z
static const RH_RF69::ModemConfigChoice MODEM_CONFIG = RH_RF69::FSK_Rb4_8Fd9_6;
// static const RH_RF69::ModemConfigChoice MODEM_CONFIG = RH_RF69::FSK_Rb2_4Fd4_8;
// static const RH_RF69::ModemConfigChoice MODEM_CONFIG = RH_RF69::FSK_Rb2Fd5;
// static const RH_RF69::ModemConfigChoice MODEM_CONFIG = RH_RF69::GFSK_Rb4_8Fd9_6;

// Transmit and Receive timeouts (millis), retry count for TX.
static const uint16_t TX_TIMEOUT = 500;
static const uint8_t TX_RETRIES = 3;
// RX timeout is without retries, essentially polls continuously over period specified
static const uint16_t RX_TIMEOUT = 1000;

// Radio Driver and Message Manager
RH_RF69 radio(RADIO_SS_PIN, RADIO_INTERRUPT_PIN);
RHReliableDatagram msgManager(radio, cfgGatewayId);

// Last message RSSI (received signal strength indicator).  0 is highest, -100
// is lowest.
int8_t lastRSSIAtGateway = 0;
int8_t lastRSSIAtNode = 0;

// radio/node Id of last message sender
uint8_t lastMsgFrom = 0;

// Intermediate string buffer for message contents.  Used as easier to work with
// than byte buffer.  KEY_LENGTH 'fudge factor' added as while length is fixed,
// an accidental overflow can be caught and handled through validation instead
// of creating an actual overflow.
char msgBuffStr[RH_RF69_MAX_MESSAGE_LEN + KEY_LENGTH] = "";

// Actual buffer used to pass payload to/from the RadioHead library.
uint8_t radioMsgBuff[RH_RF69_MAX_MESSAGE_LEN] = "";

// *****************************************************************************
//    Meter Nodes
//
// *****************************************************************************

// Maximum meter value => 4 billion entries (which may be greater than number of
// pulses depending on interval setting).  UL type will overflow at ~4.3
// billion. Could use long long but constrained to limit message size.

// Assume all meter nodes are measuring with same unit of measure (Wh).

static const uint32_t MTR_MAX_VALUE = 4000000000ul;

struct MeterNode {
    uint8_t nodeId = 0;

    // voltage in millivolts
    uint16_t battVoltageMV = 0;
    uint32_t secondsUptime = 0ul;
    uint32_t secondsSlept = 0ul;
    uint16_t freeRAM = 0;
    uint32_t lastSeenTime = 0ul;

    // crude, does not take message latency into account
    int32_t lastClockDriftSecs = 0;

    // interval in seconds at which read entries are created (resolution)
    uint8_t meterInterval = 0;
    uint32_t lastEntryFinishTime = 0ul;

    uint16_t meterImpPerKwh = 0;

    // accumulated meter count
    uint32_t lastMeterValue = 0ul;
    double lastCurrentRMS = 0.0;

    // Puck LED rate vs watched meter LED.  0=off.
    uint8_t puckLEDRate = 0;

    // Max pulse time in millis.  Ignored if longer than meter's pulse.
    uint16_t puckLEDTime = 0;

    // new values to set.  if not vals below will reset meter node...
    uint8_t newMeterInterval = 0;
    uint32_t newMeterValue = 0ul;
    uint8_t newPuckLEDRate = UINT8_MAX;
    uint16_t newPuckLEDTime = UINT16_MAX;
    uint16_t tmpGinrPollRate = 0;
    uint16_t tmpGinrPollPeriod = 0;

    // last RSSI from node
    int8_t lastNodeRSSI = 0;
};

static const uint8_t MAX_MTR_NODES = 5;       // ~50B per node

struct MeterNode meterNodes[MAX_MTR_NODES];


// *****************************************************************************
//    Timers
// *****************************************************************************

// Basetime is UNIX epoch in seconds (since 1 Jan 1970 00:00:00).
// Set from local server.
uint32_t baseTime = 0ul;

// Default UNIX epoch time.
static const uint32_t INIT_TIME = 1483228800ul;        //  1 Jan 2017 00:00:00

// Millis() value converted to seconds taken when basetime set.
uint32_t baseTimeAsLocalSecs = 0ul;

// Set using time from local Server.
uint32_t whenBooted = 0ul;


// *****************************************************************************
//    Runtime Logging
//
// *****************************************************************************

// used to detect when a new line is started, to write log level
bool newLogLine = true;


void printNewLine(LogLev logLevel){
    if (cfgLogLevel >= logLevel){
        Serial.write("\r\n");
        newLogLine = true;
    }
}


void print_P(const char* flashStr){
    strcpy_P(tmpStr, flashStr);
    Serial.write(tmpStr);
}


void println_P(const char* flashStr){
    print_P(flashStr);
    printNewLine(logNull);
}


void printLogLevel(LogLev logLevel, bool printColon){
    if (logLevel == logNull)
        return;

    if (logLevel == logError)
        print_P(LOG_ERROR_LBL);
    else if (logLevel == logWarn)
        print_P(LOG_WARN_LBL);
    else if (logLevel == logInfo)
        print_P(LOG_INFO_LBL);
    else if (logLevel == logDebug)
        print_P(LOG_DEBUG_LBL);

    if (printColon)
        Serial.write(": ");
}


void writeLog(char* debugText, LogLev logLevel){
    if (cfgLogLevel >= logLevel){
        if (newLogLine)
            printLogLevel(logLevel, true);
        Serial.write(debugText);
        newLogLine = false;
    }
}


void writeLogLn(char* debugText, LogLev logLevel){
    if (cfgLogLevel >= logLevel){
        if (newLogLine)
            printLogLevel(logLevel, true);
        Serial.write(debugText);
        printNewLine(logLevel);
    }
}


void writeLog(const char* debugText, LogLev logLevel){
    writeLog((char*)debugText, logLevel);
}


void writeLogLn(const char* debugText, LogLev logLevel){
    writeLog(debugText, logLevel);
    printNewLine(logLevel);
}


void writeLog(uint32_t debugText, LogLev logLevel){
    static char printStr[12] = "";
    sprintf(printStr, "%lu", debugText);
    writeLog(printStr, logLevel);
}


void writeLogLn(uint32_t debugText, LogLev logLevel){
    writeLog(debugText, logLevel);
    printNewLine(logLevel);
}


void writeLog(uint16_t debugText, LogLev logLevel){
    writeLog((uint32_t)debugText, logLevel);
}


void writeLogLn(uint16_t debugText, LogLev logLevel){
    writeLog((uint32_t)debugText, logLevel);
    printNewLine(logLevel);
}


void writeLog(int32_t debugText, LogLev logLevel){
    static char printStr[12] = "";
    sprintf(printStr, "%ld", debugText);
    writeLog(printStr, logLevel);
}


void writeLogLn(int32_t debugText, LogLev logLevel){
    writeLog(debugText, logLevel);
    printNewLine(logLevel);
}


void writeLog(int16_t debugText, LogLev logLevel){
    writeLog((int32_t)debugText, logLevel);
}


void writeLogLn(int16_t debugText, LogLev logLevel){
    writeLog((int32_t)debugText, logLevel);
    printNewLine(logLevel);
}


void writeLog(double debugText, LogLev logLevel){
    static char printStr[12] = "";
    // use int hack as dtostr takes up too much memory, sprintf floats
    // not supported...
    sprintf(printStr, "%d.%02d", (int)debugText, (int)(debugText*100)%100);
    writeLog(printStr, logLevel);
}


void writeLogLn(double debugText, LogLev logLevel){
    writeLog(debugText, logLevel);
    printNewLine(logLevel);
}


void writeLogF(const __FlashStringHelper* debugText, LogLev logLevel){
    // easiest to do redundant writeLog as can't simply cast FlashString

    if (cfgLogLevel >= logLevel){
        if (newLogLine)
            printLogLevel(logLevel, true);
        Serial.print(debugText);
        newLogLine = false;
    }
}


void writeLogLnF(const __FlashStringHelper* debugText, LogLev logLevel){

    if (cfgLogLevel >= logLevel){
        if (newLogLine)
            printLogLevel(logLevel, true);
        Serial.print(debugText);
    }
    printNewLine(logLevel);
}


// *****************************************************************************
//
//    Functions & Main Loop...
//
// *****************************************************************************

uint32_t getNowTimestampSec();
void resetConfig();
void printResetVal(uint8_t resetVal);

void sendRadioMsg(uint8_t recipient, bool checkReply);


void print2Digits(int digits){
    if(digits < 10)
        writeLogF(F("0"), logNull);
    writeLog(digits, logNull);
}


void printPrompt(){
    writeLogF(F(" > "), logNull);
}


void printNetworkId(){
    writeLog(cfgNetworkId1, logNull);
    writeLogF(F("."), logNull);
    writeLog(cfgNetworkId2, logNull);
    writeLogF(F("."), logNull);
    writeLog(cfgNetworkId3, logNull);
    writeLogF(F("."), logNull);
    writeLog(cfgNetworkId4, logNull);
}


void printWhValue(uint32_t whValue, LogLev logLevel){
    if (cfgLogLevel >= logLevel){
        writeLog(whValue, logNull);
        writeLogF(F(" Wh"), logNull);
    }
}


void printCmdHelp(){
    printPrompt();
    writeLogF(F("Cmds: "), logNull);
    for (uint8_t i = 0; i <= 10; i++){
        print_P((char*)pgm_read_word(&(SER_CMDS[i])));
        writeLogF(F(" "), logNull);
    }
    printNewLine(logNull);
}


bool strStartsWith(const char *strBody, const char *strPrefix){
    /*
        Tests if string starts with given prefix.  Case insensitive.
     */

    return (strncasecmp(strBody, strPrefix, strlen(strPrefix)) == 0);
}
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
void loop() {
    /*
    Do processing, comms on a prioritised basis, ensuring at least 5 iterations
    before sleeping.
    */

    static uint8_t doEvery = 0;

    for (doEvery = 1; doEvery <=5; doEvery++){
        // do every time
        checkSerialInput();
        wdt_reset();
        checkButton();

        // do processing if not in middle of serial input
        if (serialBuffPos == 0 && doEvery % 2 == 0)
            checkRadioMsg();

        if (serialBuffPos == 0 && doEvery == 5)
            checkNodeLife();
    }
}

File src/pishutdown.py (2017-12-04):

# script to implement RPi shutdown and reboot on GPIO-connected button press
from subprocess import call
import RPi.GPIO as GPIO
import os
import time

# Define a function to run when an interrupt is called
def shutdown(pin):
    print("shutting down")
    os.system("sudo shutdown -h now") # Shutdown command

def reboot(pin):
    print("rebooting")
    os.system("sudo reboot") # Reboot command

GPIO.setmode(GPIO.BCM) # Set pin numbering to board numbering
GPIO.setup(23, GPIO.IN)		# already have pullup
GPIO.add_event_detect(23, GPIO.FALLING, callback=shutdown, bouncetime=200) #Set up an interrupt to look for button presses
GPIO.setup(24, GPIO.IN)         # already have pullup
GPIO.add_event_detect(24, GPIO.FALLING, callback=reboot, bouncetime=200) #Set up an interrupt to look for button presses

while True:
    time.sleep(.5)
